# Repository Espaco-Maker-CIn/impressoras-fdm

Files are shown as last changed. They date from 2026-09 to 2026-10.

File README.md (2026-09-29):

# Documentação do Laboratório

Repositório central de manuais, configurações e instruções.
Se você não sabe por onde começar, use o índice abaixo.

## Impressoras 3D (kit Klipper + Orbiter)

Todas as impressoras usam o mesmo kit de upgrade. Manuais e
configurações de cada máquina estão em [printer](printers).

- [Manual de revitalização (PDF)](printers/manual-revitalizacao.pdf)
- [Manual de instalação do printer.cfg](printers/manual-instalacao-cfg.md)
- [Configuração de cada impressora](printers/configs)

## Adaptações 3D

Adaptações que foram feitas para impressoras:
[adaptacoes-3d](adaptacoes-3d)

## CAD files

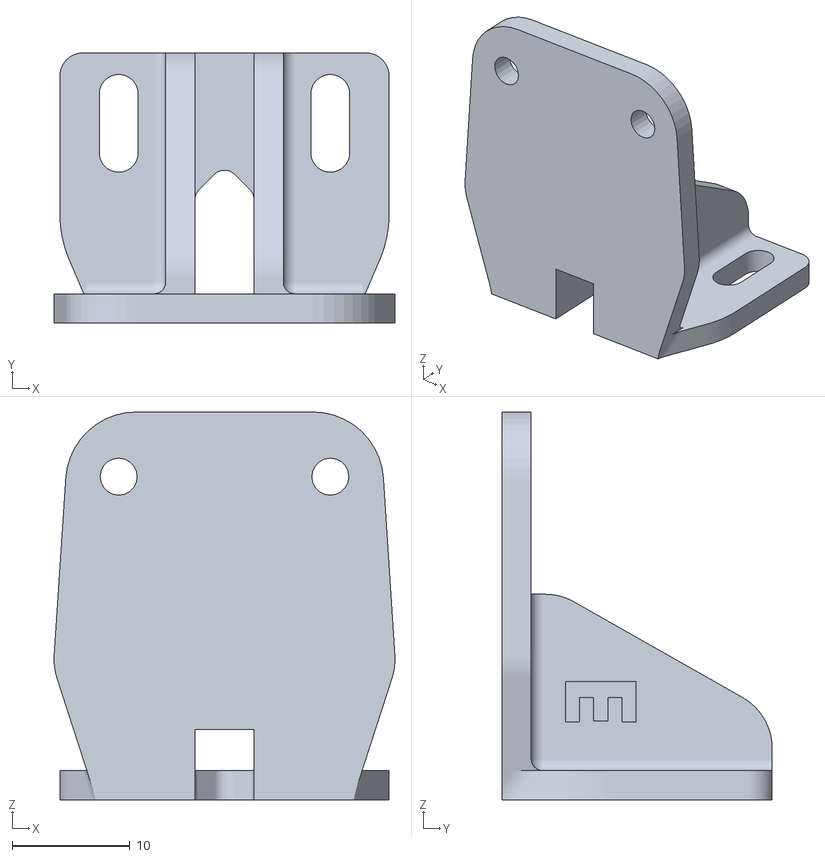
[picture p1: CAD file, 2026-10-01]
adaptacoes-3d/DDE BLtouch_adjustablev1.stl
29.0 x 23.0 x 33.0

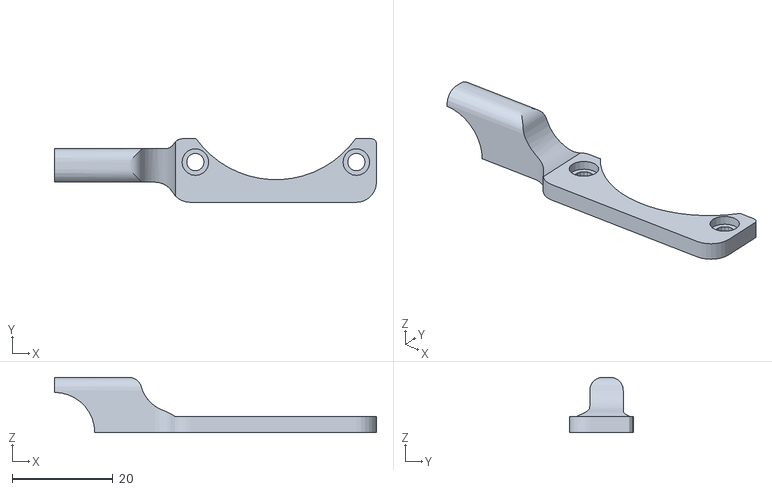
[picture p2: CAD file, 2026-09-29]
adaptacoes-3d/ender-3-v2-neo-fim-de-curso-X/adaptador-fim-de-curso-X.stl
64.0 x 12.6 x 11.0

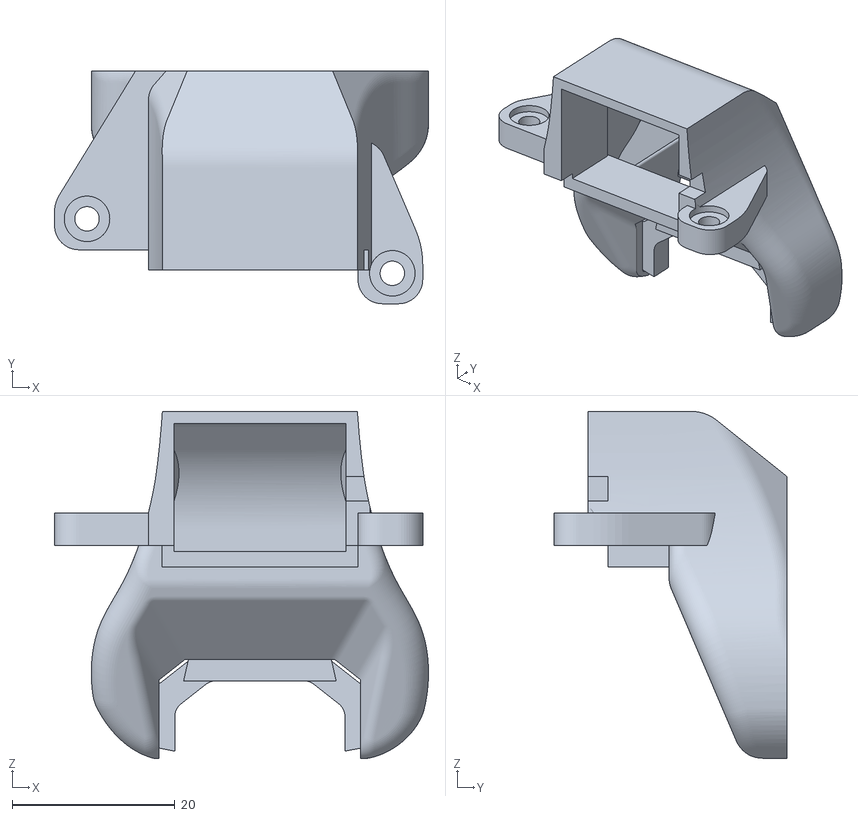
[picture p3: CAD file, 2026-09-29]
adaptacoes-3d/DDE-fan-shroud-volcano-V1.5.STL
46.0 x 28.6 x 42.7

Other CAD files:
adaptacoes-3d/ender-3-v2-neo-fim-de-curso-X/40x40x10 DC Fan.ipt
adaptacoes-3d/ender-3-v2-neo-fim-de-curso-X/OldVersions/40x40x10 DC Fan.0001.ipt

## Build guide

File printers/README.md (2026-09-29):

# Impressoras 3D: kit Klipper + Orbiter

## Manuais

- [Revitalização (PDF)](manual-revitalizacao.pdf): serve para todas as máquinas.
- [Instalação do printer.cfg](manual-instalacao-cfg.md): serve para todas as máquinas.

## Máquinas

| Etiqueta | Modelo | Arquivo de configuração | Observações |
|---|---|---|---|
| ender-3-v2-00 | Ender 3 V2 | [configs/ender-3-v2-00.cfg](configs/ender-3-v2-00.cfg) | |
| ender-3-v2-01 | Ender 3 V2 | [configs/ender-3-v2-01.cfg](configs/ender-3-v2-01.cfg) | |
| ender-3-v2-neo-00 | Ender 3 V2 Neo | [configs/ender-3-v2-neo-00.cfg](configs/ender-3-v2-neo-00.cfg) | |
| ender-3-v2-neo-01 | Ender 3 V2 Neo | [configs/ender-3-v2-neo-01.cfg](configs/ender-3-v2-neo-01.cfg) | |
| ender-7 | Ender 7 | [configs/ender-7.cfg](configs/ender-7.cfg) | |
| ender-5 | Ender 5 | [configs/ender-5.cfg](configs/ender-5.cfg) | |

## Regras para o printer.cfg

- Um arquivo por máquina, com o mesmo nome da etiqueta colada nela.
- Ao mudar algo, escreva no commit qual máquina e o motivo.
- Não coloque senhas nem dados de rede nos arquivos!

## O kit upgrade:

Todas as impressoras foram convertidas com o mesmo kit:

- Firmware: Klipper
- Extrusor: direct drive Orbiter
- Hotend: tipo V6 / Volcano
- Placa controladora: BIGTREETECH SKR Mini E3 V3.0
- Computador de bordo: Raspberry Pi executando o Klipper

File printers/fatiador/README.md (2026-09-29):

# Perfis do fatiador

Perfis prontos para importar no fatiador. Eles são independentes do
`printer.cfg`, mas trabalham em conjunto com ele.

## Fatiador usado

- Nome e versão: OrcaSlicer 4.2.4

## Como importar

1. Baixe os arquivos da pasta do fatiador.
2. No fatiador, importe primeiro o perfil da **impressora**,
   depois os de **filamento** e **qualidade**.
3. Selecione o conjunto correto na tela principal antes de fatiar.

## Perfis disponíveis

### Impressora

| Arquivo | Modelo | Observações |
|---|---|---|
| ender-3-v2.json | Ender 3 V2 | |
| ender-3-v2-neo.json | Ender 3 V2 Neo | |
| ender-7.json | Ender 7 | |
| ender-5.json | Ender 5 | |

### Filamento

| Arquivo | Material | Marca testada | Hotend | Temperatura bico / mesa |
|---|---|---|---|---|
| pla.json | PLA | (preencher) | V6 / Volcano | (preencher) |
| petg.json | PETG | (preencher) | V6 / Volcano | (preencher) |

### Qualidade

| Arquivo | Altura de camada | Uso recomendado |
|---|---|---|
| 0.12mm-fino.json | 0,12 mm | Detalhes finos |
| 0.20mm-padrao.json | 0,20 mm | Uso geral |
| 0.28mm-rapido.json | 0,28 mm | Protótipos rápidos |

## Ligação com o printer.cfg

- O G-code inicial dos perfis de impressora chama: (preencher, ex.: START_PRINT)
- Se mudar a macro no `printer.cfg`, atualize o perfil da impressora também.

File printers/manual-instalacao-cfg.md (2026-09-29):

# Instalação do printer.cfg

Este manual vale para todas as impressoras do kit Klipper + Orbiter.

## Antes de começar

- Klipper já instalado no Raspberry Pi
- Placa SKR Mini E3 V3.0 com o firmware do Klipper gravado
- Acesso à interface web (Mainsail)

## Passo a passo

1. Abra a interface web da impressora (com o IP dela).
2. No painel esquerdo procure por (Machine ou Maquina).
3. Substitua o conteúdo do `printer.cfg` pelo arquivo da sua máquina,
   em `printer/configs/`. (nao exclua o printer.cfg, no lugar, acesse-o e substitua o conteudo com ctrl+A + ctrl+V).
4. Clique em salvar e reiniciar (Save & Restart).
5. Confira se a impressora conecta sem erros.

## O que ajustar depois de instalar

- (preencher: calibração do Z offset, PID, esteps do extrusor...)

## Problemas comuns

- (preencher conforme aparecerem)

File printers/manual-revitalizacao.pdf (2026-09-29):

# Manual de Uso Simples

# Revitalização Impressora 3d

# Manual de Uso Simples

# Revitalização Impressora 3d

## Recife | 2026

## Edmundo Paiva

## Pedro Salman

## Coordenação de Extensão

©2026 by Centro de Informática - UFPE

## EXPEDIENTE

Reitor: Alfredo Macedo Gomes
Diretor do Centro de Informático: Sérgio Soares Vice-Diretor do Centro de Informático: Ricardo Massa Coordenador: Felipe Calegario

Apoio Técnico
Centro de Informática - UFPE

GUIA DO INICIANTE FABLAB:

ImprEssOrA 3D

Uma impressora 3D é, na prática, um conjunto de sistemas que precisam trabalhar de

forma integrada. Estrutura mecânica, eletrônica, firmware, motores, sensores e controle

térmico dependem uns dos outros para que uma peça seja produzida com qualidade e

segurança. Quando um desses sistemas se torna limitado ou obsoleto, muitas vezes

não | é necessário | substituir | toda | a | máquina: é possível | compreender | seu

funcionamento, identificar suas limitações e modernizá-la.

É justamente essa proposta que orienta este manual. A revitalização apresentada aqui

envolve a substituição de componentes mecânicos e eletrônicos da impressora, com a

instalação de um sistema de extrusão Direct Drive utilizando o Orbiter, hotend Volcano,

placa controladora BIGTREETECH SKR Mini E3 V3.0 e uma Raspberry Pi executando o

Klipper. O objetivo não é apenas fazer a impressora voltar a funcionar, mas transformá-

la em uma plataforma mais atual, configurável e adequada às necessidades do Espaço

Maker.

Durante o processo, diferentes áreas da engenharia se encontram. É necessário

compreender | montagem | mecânica, ajustes, organização | de | cabos, alimentação

elétrica, comunicação entre dispositivos, sistemas Linux e configuração de firmware.

Cada etapa permite observar como decisões aparentemente simples podem influenciar

diretamente o funcionamento e o desempenho final do equipamento.

Esse tipo de atividade representa bem a proposta do Espaço Maker: aprender

entendendo o equipamento, desmontando, modificando, testando e documentando

cada solução encontrada. Mais do que seguir uma sequência de montagem, este

manual busca registrar um processo que possa ser reproduzido, compreendido e

aprimorado por outras pessoas no futuro.

# Apresentação

Pedro Salman

Manager do Espaço Maker 2026

# Sumário

GUIA DO INICIANTE FABLAB:

ImprEssOrA 3D

1. Introdução
2. Lista de Materiais
3. Hardware

3.1 Preparação do conjunto do cabeçote

3.2 Substituição do carro de movimentação do eixo X

3.3 Instalação das porcas nas peças impressas

3.4 Instalação do ventilador 4010

3.5 Montagem das peças impressas e adaptação para o hotend Volcano

3.6 Fixação da base no carro de movimentação

3.7 Instalação do hotend Volcano

3.8 Instalação do tubo de PTFE

3.9 Fechamento do cabeçote

3.10 Instalação do extrusor Orbiter

3.11 Instalação do duto de ventilação e ventilador 5015

3.12 Organização do chicote

3.13 Conexões na BTT SKR Mini E3 V3.0

4. Firmware

4.1 Funcionamento do sistema Klipper

4.2 Preparação do cartão microSD

4.3 Instalação do MainsailOS

4.4 Configuração inicial do MainsailOS

4.5 Primeiro boot da Raspberry Pi

4.6 Identificação do endereço IP da Raspberry Pi

4.7 Acesso à Raspberry Pi por SSH

4.8 Instalação do KIAUH

4.9 Atualização dos componentes

4.10 Configuração do firmware da BTT SKR Mini E3 V3.0

4.11 Compilação e transferência do firmware com WinSCP

4.12 Gravação do firmware na BTT SKR Mini E3 V3.0

4.13 Conexão da Raspberry Pi à BTT SKR Mini E3 V3.0

4.14 Identificação da MCU

# Sumário

# Introdução

GUIA DO INICIANTE FABLAB:

ImprEssOrA 3D

# 1 Introdução

Este | manual | apresenta | o | procedimento | de | montagem | e | configuração | do | sistema

klipper+orbiter, utilizado na impressora 3D equipada com extrusor direct drive Orbiter, hotend

do tipo V6/Volcano, placa controladora BIGTREETECH SKR Mini E3 V3.0 e Raspberry Pi

executando o sistema Klipper.

O procedimento foi dividido em duas etapas principais: Hardware e Firmware.

Na primeira parte são apresentados os procedimentos necessários para montagem do carro de

movimentação, instalação do hotend, extrusor Orbiter, ventiladores e organização dos cabos.

Ao final, são apresentadas as conexões elétricas necessárias entre o novo conjunto e a placa

controladora.

Na segunda parte é apresentada a instalação do Klipper, começando pela preparação da

Raspberry Pi com o MainsailOS, configuração da rede, acesso via SSH, utilização do KIAUH e

compilação do firmware específico para a placa SKR Mini E3 V3.0.

O objetivo é permitir que todo o processo seja realizado de forma padronizada e reproduzível,

evitando erros de montagem, conexões incorretas e configurações incompatíveis entre a

Raspberry Pi e a placa controladora.

# Lista de Materiais

# 2 Lista de Materiais

Para a montagem do cabeçote serão utilizados:

Carro de movimentação compatível com Ender 3;

conjunto de peças impressas do DDE;

extrusor Orbiter;

hotend Volcano;

tubo de PTFE;

duto de ventilação;

porcas M3 quadradas;

porcas M3 sextavadas;

parafusos M3;

abraçadeiras plásticas;

malha para organização dos cabos.

kit duplo z, caso a impressora não possua (https://www.youtube.com/watch?v=rGkWkHWJFVs&t=322s)

Os componentes eletrônicos que serão utilizados:

placa BIGTREETECH SKR Mini E3 V3.0;

Raspberry Pi;

cartão microSD para a Raspberry Pi;

cartão microSD para a placa controladora;

ventilador axial 4010;

ventilador radial 5015;

motor do extrusor Orbiter;

cartucho aquecedor do hotend;

termistor;

cabo USB para comunicação entre a Raspberry Pi e a SKR Mini E3 V3.0.

Para utilização da Raspberry Pi 2 através de rede sem fio também será necessário um adaptador

Wi-Fi USB compatível com Linux. Alternativamente, a configuração inicial pode ser realizada por

conexão Ethernet.

As ferramentas necessárias para a montagem serão utilizadas principalmente:

chaves Allen;

chave Phillips;

alicate de corte;

abraçadeiras;

paquímetro;

ferramenta para acabamento da peça impressa;

computador com leitor de cartão microSD.

# Hardware

# 3 Hardware

3.1 Preparação do conjunto do cabeçote

Antes de realizar qualquer montagem ou alteração elétrica, desligue completamente a

impressora e desconecte-a da alimentação.

Nunca conecte ou desconecte motores de passo com a placa energizada.

Antes da montagem, confira todos os componentes do conjunto.

Verifique principalmente se as peças impressas não apresentam trincas, deformações ou

problemas nos alojamentos destinados às porcas.

Separe os parafusos e porcas por tamanho para facilitar as próximas etapas.

A TriangleLab recomenda realizar essa inspeção antes da montagem e começar pela

preparação das peças superior e inferior do cabeçote.

Figura 1: Componentes utilizados na montagem do cabeçote

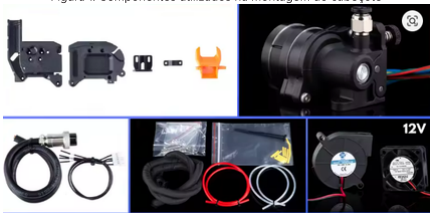
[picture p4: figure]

3.2 Substituição do carro de movimentação do eixo X

O primeiro passo da modificação será substituir o carro de movimentação atualmente instalado

pelo carro utilizado na Ender 3, necessário para fixação correta do conjunto DDE.

Passo a passo

1.Retire o cabeçote atualmente instalado.

2.Libere os cabos presos ao carro.

3.Solte a correia do eixo X.

4.Retire o carro de movimentação existente.

5.Instale o carro de movimentação da Ender 3.

6.Reinstale a correia.

7.Ajuste a porca excêntrica das rodas até eliminar a folga.

8.Movimente manualmente o carro por todo o eixo X.

O carro deve movimentar-se livremente, sem folgas e sem exigir força excessiva.

Figura 2: Verificação do movimento do novo carro

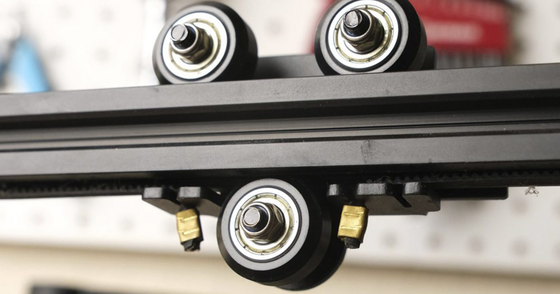
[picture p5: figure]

3.3 Instalação das porcas nas peças impressas

As peças impressas possuem alojamentos destinados às porcas utilizadas posteriormente na

montagem.

Existem alojamentos para porcas quadradas e sextavadas.

Passo a passo:

1.Identifique todos os alojamentos presentes nas peças.

2.Insira as porcas M3 quadradas nos alojamentos correspondentes.

3.Insira as porcas M3 sextavadas nos alojamentos sextavados.

4.Pressione as porcas até o fundo.

5.Caso seja necessário, utilize um parafuso M3 longo para auxiliar no encaixe.

6.Confirme que as porcas estão alinhadas e firmemente presas.

Essa preparação segue a montagem original da TriangleLab, que utiliza porcas M3 inseridas

diretamente nas cavidades das peças impressas.

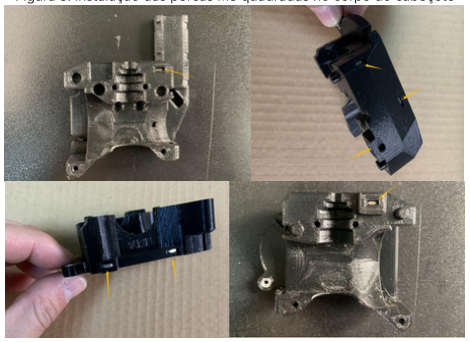
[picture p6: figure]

Figura 3: Instalação das porcas M3 quadradas no corpo do cabeçote

Figura 4: Instalação das porcas M3 quadradas no corpo do cabeçote

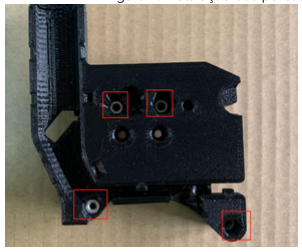
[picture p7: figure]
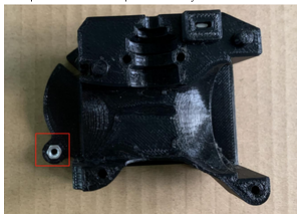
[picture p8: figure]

3.4 Instalação do ventilador 4010

O ventilador axial 4010 é responsável pela refrigeração da região fria do hotend.

Passo a passo

1.Posicione o ventilador no alojamento lateral da base.

2.Verifique o sentido do fluxo de ar.

3.Passe o cabo pelo canal horizontal existente na peça.

4.Fixe inicialmente o ventilador utilizando os parafusos M3 14 mm.

O manual original também direciona os fios do 4010 pelo canal lateral da peça antes do

fechamento do cabeçote.

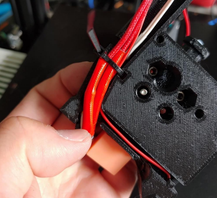
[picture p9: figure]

Figura 5: Ventilador 4010 instalado na base

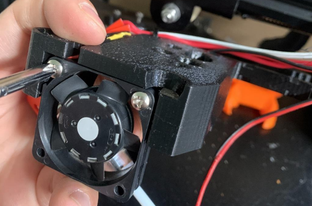
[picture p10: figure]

3.5 Montagem das peças impressas na base

Após a instalação das porcas, as diferentes peças impressas que compõem a estrutura interna

deverão ser inseridas na base do cabeçote.

Passo a passo:

1.Realize a adaptação para o hotend volcano, no ponto onde a entrada pneumatica tocaria.

2.Identifique a orientação de cada peça.

3.Posicione a primeira peça no encaixe correspondente.

4.Alinhe os furos com as porcas instaladas anteriormente.

5.Instale os parafusos necessários inicialmente sem realizar o aperto final.

6.Verifique se todas as peças estão completamente encaixadas e realize o ultimo aperto.

Figura 6: Peças impressas instaladas na base do cabeçote

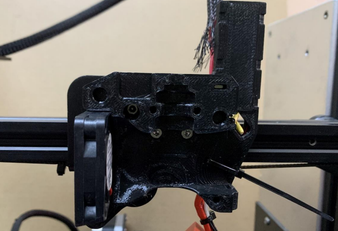
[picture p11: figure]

3.6 Instalação do hotend Volcano

Após realizar a adaptação da peça interna, o hotend Volcano poderá ser instalado.

Passo a passo

1.Posicione o hotend no alojamento.

2.Confirme o encaixe na peça adaptada.

3.Passe os fios do cartucho aquecedor pelo canal destinado ao chicote.

4.Passe também os fios do termistor.

5.Organize os cabos dentro da peça, eles nao podem estar dobrados.

6.Utilize uma abraçadeira para mantê-los posicionados.

7.Confirme que nenhum cabo encosta diretamente no bloco aquecedor.

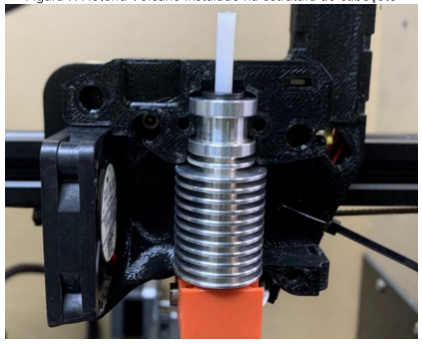
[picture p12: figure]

Figura 7: Hotend Volcano instalado na estrutura do cabeçote

3.7 Instalação do tubo de PTFE

O tubo de PTFE fará a ligação entre o extrusor Orbiter e o hotend.

Passo a passo

1.Corte o PTFE perpendicularmente.

2.Insira o tubo completamente no hotend.

3.Posicione temporariamente o Orbiter sobre o conjunto.

4.Verifique o comprimento necessário.

5.Ajuste o tubo de forma que não exista folga entre o extrusor e o hotend.

No conjunto V6 original, a TriangleLab especifica tubo de aproximadamente 52 a 52,5 mm, com

aproximadamente 11 mm expostos acima do corpo.

Como neste projeto a peça interna será modificada para o Volcano, essa dimensão deverá ser

confirmada no conjunto real antes de ser utilizada como medida definitiva.

Figura 8: Verificação do tubo de PTFE

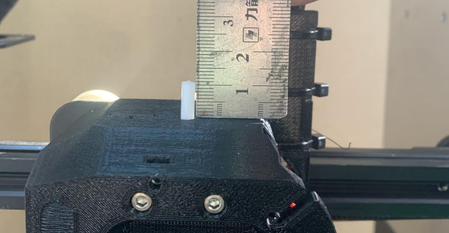
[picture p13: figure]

3.8 Fechamento do cabeçote

Após verificar a posição dos componentes internos, feche o conjunto.

Passo a passo

1.Organize os cabos dentro dos canais.

2.Verifique se nenhuma porca saiu do alojamento.

3.Posicione a parte superior do cabeçote.

4.Instale os quatro parafusos M3 × 35.

5.Aperte-os alternadamente.

6.Finalize a fixação do ventilador 4010.

A montagem original utiliza quatro parafusos M3 × 35 para unir as partes superior e inferior.

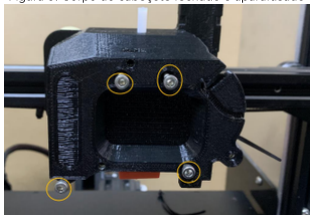
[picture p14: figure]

O Orbiter será instalado diretamente acima do hotend, formando o sistema Direct Drive.

Passo a passo

1.Caso o orbiter esteja desmontado, monte ele junto a caixa planetaria de redução, de forma

com que os cabos saiam para cima. As engrenganes devem engrenar suavemente.

2.Posicione o extrusor sobre o cabeçote.

3.Alinhe a saída do filamento com o tubo de PTFE.

4.Encaixe cuidadosamente o tubo.

5.Instale os dois parafusos M3 × 10.

6.Aperte os parafusos.

7.Verifique se o caminho do filamento está alinhado.

A TriangleLab utiliza dois parafusos M3 × 10 para realizar essa fixação.

Figura 9: Corpo do cabeçote fechado e aparafusado

3.9 Instalação do extrusor Orbiter

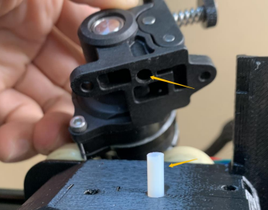
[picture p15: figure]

Figura 10: Extrusor Orbiter instalado sobre o cabeçote

3.10 Instalação do duto de ventilação

O duto direciona o ar proveniente do ventilador 5015 para a região de impressão.

Passo a passo

1. Imprima o duto para o extrusor volcano, ele se encontra anexado nessa mensagem. (https://drive.google.com/drive/folders/1piNkyhIdt_dpDcW6czVUYIUVgL8tmZOw)

2.Posicione o duto na parte inferior do cabeçote.

3.Alinhe seus pontos de fixação.

4.Instale os parafusos M3 × 10.

5.Verifique a posição da saída de ar.

6.Confirme que o duto não encosta no bloco aquecedor do Volcano.

7.Instale em seguida o ventilador 5015, e a fixe em seus repectivos parafusos.

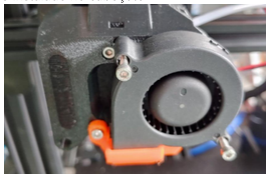
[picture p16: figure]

Figura 11: Duto e ventilador 5015 instalado no cabeçote

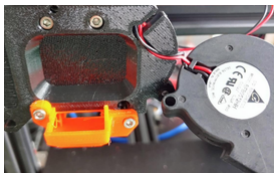
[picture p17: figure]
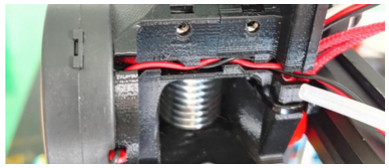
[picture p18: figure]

3.11 Organização do chicote

Todos os cabos do cabeçote deverão ser organizados formando um único chicote.

Passo a passo

1.Agrupe os fios do motor, ventiladores, termistor e cartucho aquecedor.

2.Posicione o elemento de sustentação do chicote.

3.Passe os cabos pela malha de proteção.

4.Fixe a malha ao cabeçote utilizando abraçadeiras.

5.Movimente manualmente o eixo X de uma extremidade à outra.

6.Verifique se o chicote acompanha todo o movimento sem ser tensionado.

7.Confirme que nenhum fio toca as rodas do carro.

O manual da TriangleLab chama atenção especificamente para evitar que os fios do motor

encostem nas rodas ou no perfil do eixo X.

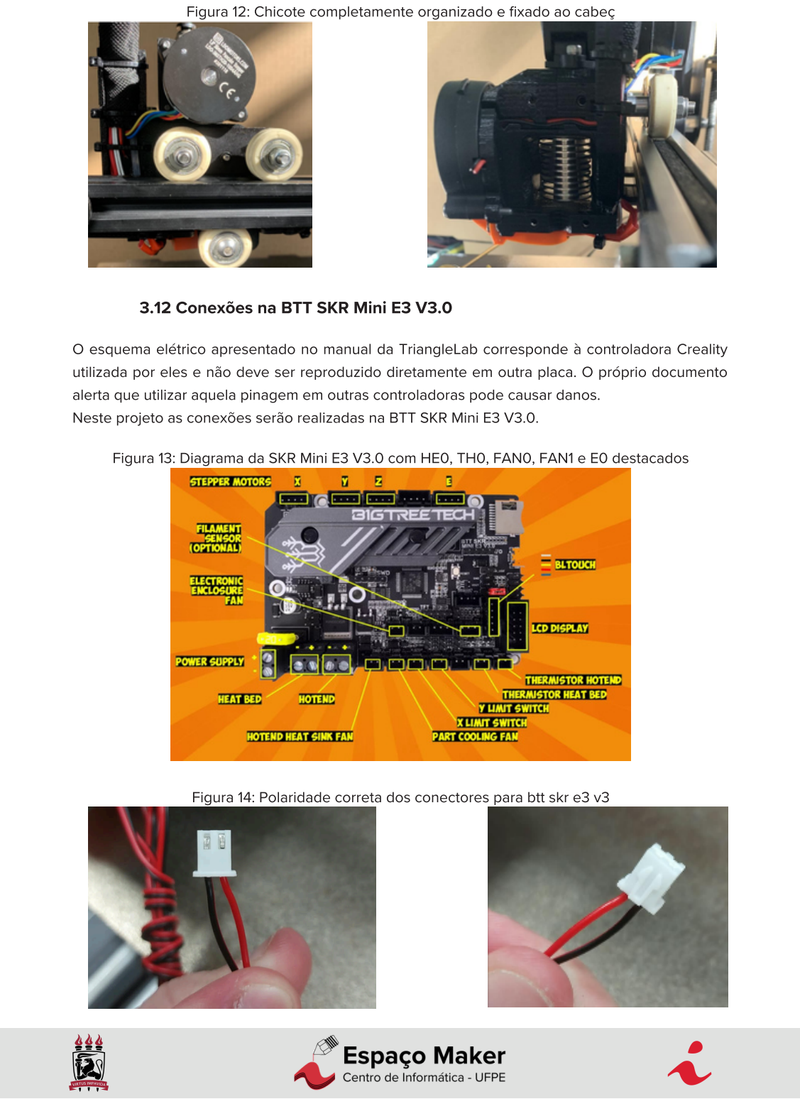
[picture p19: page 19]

O esquema elétrico apresentado no manual da TriangleLab corresponde à controladora Creality

utilizada por eles e não deve ser reproduzido diretamente em outra placa. O próprio documento

alerta que utilizar aquela pinagem em outras controladoras pode causar danos.

Neste projeto as conexões serão realizadas na BTT SKR Mini E3 V3.0.

Figura 12: Chicote completamente organizado e fixado ao cabeç

3.12 Conexões na BTT SKR Mini E3 V3.0

Figura 13: Diagrama da SKR Mini E3 V3.0 com HE0, TH0, FAN0, FAN1 e E0 destacados

Figura 14: Polaridade correta dos conectores para btt skr e3 v3

# Firmware

N (https://raspberry-pi-imager.br.uptodown.com/windows/download/109117164)o Raspberry Pi Imager, versão 1.7.5: (https://raspberry-pi-imager.br.uptodown.com/windows/download/109117164)

1.Selecione o sistema operacional.

2.Acesse Other specific-purpose OS.

3.Selecione a categoria destinada à impressão 3D.

4.Selecione MainsailOS.

5.Escolha a versão compatível com a Raspberry Pi utilizada.

6.Selecione o cartão microSD.

Essa é a sequência apresentada no vídeo utilizado como referência para a instalação.

Para a Rasp 2, é utilizado o mainsail 32bits, mas para outras placas, costumam se utilizar sistemas

64bits.

Será utilizado um cartão microSD para armazenar o sistema operacional da Raspberry Pi.

Passo a passo

1.Insira o cartão no computador.

2.Abra o Raspberry Pi Imager.

3.Confirme se o cartão correto foi reconhecido.

4.Prepare-se para selecionar o MainsailOS.

A gravação apagará os arquivos existentes no cartão.

# 4 Firmware

4.1 Preparação do cartão microSD

O sistema será dividido entre a Raspberry Pi e a placa controladora.

A Raspberry Pi executará os serviços responsáveis pelo Klipper (https://www.youtube.com/watch?v=_8r87gBFOy8) e pela interface de controle.

A SKR Mini E3 V3.0 executará o firmware da MCU e ficará responsável pelo controle direto dos

motores, aquecedores, sensores e ventiladores.

A comunicação entre os dois dispositivos será realizada por USB.

Figura 4: Tipos de solda

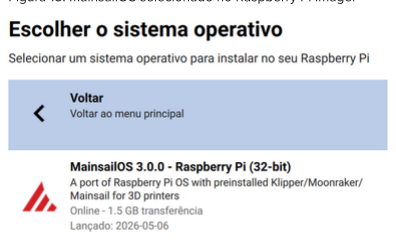
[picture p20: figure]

Figura 15: MainsailOS selecionado no Raspberry Pi Imager

4.2 Instalação do MainsailOS

4.3 Configuração inicial do MainsailOS

Antes de gravar o cartão, abra as opções de personalização.

Configure:

nome do dispositivo;

usuário;

senha;

acesso SSH;

rede, quando aplicável;

localização;

fuso horário.

O SSH deverá permanecer habilitado, pois será necessário posteriormente.

Figura 16: Configurações de hostname, usuário, rede e SSH

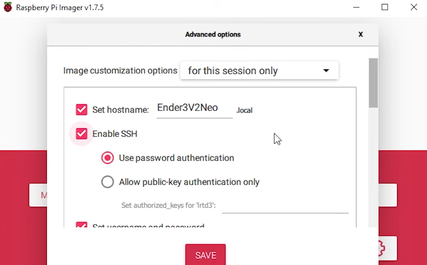
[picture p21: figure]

4.4 Primeiro boot da Raspberry Pi

Após concluir a gravação:

1.Remova o cartão do computador.

2.Insira-o na Raspberry Pi.

3.Conecte a Raspberry Pi à rede.

4.Conecte sua alimentação.

5.Aguarde a inicialização.

O primeiro boot poderá demorar alguns minutos.

4.5 Acesso ao Mainsail

Após concluir a gravação:

1.Conecte a rasp via ethernet ou wi-fi préconfigurada.

2.Conecte o cabo hdmi e teclado para conseguir digitar no terminal

3.coloque o login e senha, para logar.

4. Digite “ hostname -I “ para descobrir o ip da rede da rasp.( i maiusculo)
5. O ip será algo como 172.X.X.X.
6. Com esse ip, e quando estiver na mesma rede da rasp, voce consegue acessar via ssh.
7. Existe inumeros softwares para ter esse acesso, recomendo o putty. (https://www.chiark.greenend.org.uk/~sgtatham/putty/latest.html)

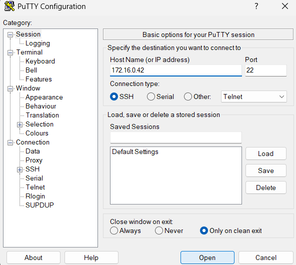
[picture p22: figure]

O KIAUH — Klipper Installation And Update Helper será utilizado para auxiliar na manutenção e

atualização dos componentes do sistema.

Primeiramente, atualize a lista de pacotes e instale o Git:

sudo apt-get update && sudo apt-get install git -y

Depois faça o download do KIAUH:

cd ~ && git clone https://github.com/dw-0/kiauh.git

Execute:

./kiauh/kiauh.sh

Esses são os comandos apresentados pelo próprio projeto KIAUH, e deve aparecer algo como:

Figura 17: Tela inicial Putty

4.6 Instalação do KIAUH

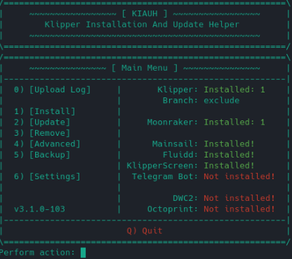
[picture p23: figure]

Figura 18: Tela inicial KIAUH

4.7 Atualização dos componentes

No menu principal do KIAUH, acesse a opção destinada às atualizações.

Verifique os componentes instalados e atualize os que apresentarem novas versões,

principalmente:

Klipper;

Moonraker;

Mainsail;

KIAUH.

Os números das opções podem variar entre versões. Por isso, utilize os nomes exibidos no menu

e não uma sequência numérica fixa.

O KIAUH identifica Klipper, Moonraker e Mainsail entre seus componentes principais.

Você deve precionar o numero 2 para ir ao menu de update, e lá, aceitar todos eles, isso irá

demorar alguns minutos.

Figura 19: Menu de atualização do KIAUH

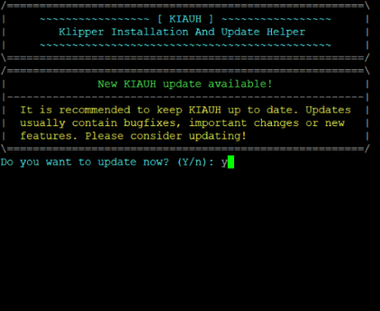
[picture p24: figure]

4.8 Configuração do firmware da SKR Mini E3 V3.0

Após as atualizações, acesse a pasta do Klipper:

cd ~/klipper

Execute:

make menuconfig

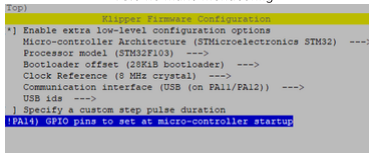
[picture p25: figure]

Com a configuração salva, execute:

make

Aguarde o término da compilação. O arquivo será gerado em: ~/klipper/out/klipper.bin

Esse arquivo está armazenado na Raspberry Pi e deverá ser transferido para o computador antes

de ser colocado no cartão microSD da SKR Mini E3 V3.0.

Para retirar o arquivo da Raspberry Pi será utilizado o WinSCP, (https://winscp.net/eng/download.php) que permite acessar os arquivos

da Raspberry Pi através da rede.

1.Abra o WinSCP no computador.

2.Na tela de conexão, selecione:

Protocolo de arquivo: SFTP

Nome do servidor: Utilize o endereço IP da Raspberry Pi 172.x.X.X

Porta: 22

1.Informe o mesmo usuário e senha utilizados para acessar a Raspberry Pi através do SSH.

2.Clique em Login.

Na primeira conexão poderá ser apresentada uma mensagem solicitando confirmação da chave

do servidor. Confirme para continuar.

Após a conexão, o WinSCP apresentará duas áreas principais:

lado esquerdo: arquivos do computador;

lado direito: arquivos da Raspberry Pi.

Para a BTT SKR Mini E3 V3.0, configure:

Enable extra low-level configuration options

Micro-controller Architecture

STMicroelectronics STM32

Processor model

STM32G0B1

Bootloader offset

8KiB bootloader

Clock Reference

8 MHz crystal

Communication interface

USB (on PA11/PA12)

Figura 20: Configuração da SKR Mini E3

V3.0 no make menuconfig

4.9 Compilação do firmware

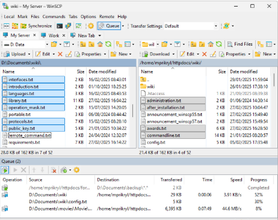
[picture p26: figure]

No lado correspondente à Raspberry Pi, acesse a pasta:

/home/USUARIO/klipper/out/

Localize o arquivo:

klipper.bin

No lado esquerdo do WinSCP, abra uma pasta do computador onde o arquivo será salvo.

Arraste o arquivo klipper.bin do lado da Raspberry Pi para o lado do computador.

Aguarde a conclusão da transferência.

O arquivo de firmware agora estará armazenado no computador e poderá ser preparado para

gravação na SKR Mini E3 V3.0.

Insira um cartão microSD no computador, formatado adequadamente, e coloque o firmware.bin

diretamente na raiz.

A SKR Mini E3 V3.0 necessita que o arquivo gerado pelo Klipper seja renomeado para

firmware.bin antes da atualização por cartão.

Figura 21: Transferência do klipper.bin utilizando o WinSCP

Passo a passo

1.Desligue completamente a impressora.

2.Insira o cartão microSD na SKR Mini E3 V3.0.

3.Ligue a impressora.

4.Aguarde a inicialização da placa.

5.Desligue novamente o equipamento.

Após a gravação, conecte a Raspberry Pi à interface Micro-USB da SKR Mini E3 V3.0. Utilize um

cabo USB capaz de transmitir dados. Ligue novamente os equipamentos.

4.10 Gravação do firmware na SKR Mini E3 V3.0

Abra o Mainsail via navegador ou orcaslicer.

A presença da SKR Mini E3 V3.0 no comando anterior confirma que:

a Raspberry Pi está operacional;

o Klipper está instalado;

o firmware da MCU foi compilado;

a SKR recebeu o firmware;

a comunicação USB está funcionando.

A configuração específica da impressora será realizada posteriormente através do arquivo

printer.cfg.

Nele serão configurados os motores, termistores, ventiladores, extrusor Orbiter, limites de

movimento e demais parâmetros da máquina.

4.11 Identificação da MCU

Acesse novamente a Raspberry Pi por SSH.

ls /dev/serial/by-id/*

Deverá aparecer um endereço semelhante a:

/dev/serial/by-id/usb-Klipper_stm32g0b1xx_XXXXXXXXXXXX-if00

Copie exatamente o endereço apresentado.

Posteriormente ele será inserido no printer.cfg, por exemplo:

[mcu]

serial: /dev/serial/by-id/usb-Klipper_stm32g0b1xx_XXXXXXXXXXXX-if00

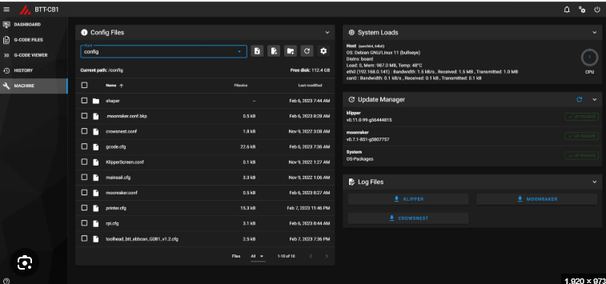
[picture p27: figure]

Figura 22: Interface do Mainsail

4.12 Configuração do firmware da SKR Mini E3 V3.0

©2026 by Centro de Informática - UFPE

# Manual de Uso Simples

# Revitalização Impressora 3d

## Recife | 2026

## Edmundo Paiva

## Pedro Salman

## Coordenação de Extensão

# Contato

## espacomaker.cin.ufpe.br

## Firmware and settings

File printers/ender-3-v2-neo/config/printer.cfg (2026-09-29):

# This file contains common pin mappings for the BIGTREETECH SKR mini
# E3 v3.0. To use this config, the firmware should be compiled for the
# STM32G0B1 with a "8KiB bootloader" and USB communication/USART.
#
# The "make flash" command does not work on the SKR mini E3. Instead,
# after running "make", copy the generated "out/klipper.bin" file to a
# file named "firmware.bin" on an SD card and then restart the SKR
# mini E3 with that SD card.
#
# See docs/Config_Reference.md for a description of parameters.


[include mainsail.cfg]


# ================================================================
# MCU
# ================================================================

[mcu]
serial: /dev/serial/by-id/usb-Klipper_stm32g0b1xx_390027000C50564837383420-if00
# serial: /dev/ttyAMA0
# restart_method: command


# ================================================================
# PRINTER
# ================================================================

[printer]
kinematics: cartesian
max_velocity: 300
max_accel: 5000
max_z_velocity: 5
max_z_accel: 70


# ================================================================
# EIXO X
# ================================================================

[stepper_x]
step_pin: PB13
dir_pin: !PB12
enable_pin: !PB14
microsteps: 16
rotation_distance: 40
endstop_pin: ^PC0
position_endstop: 0
position_max: 200
homing_speed: 50

[tmc2209 stepper_x]
uart_pin: PC11
tx_pin: PC10
uart_address: 0
run_current: 0.580
hold_current: 0.500
stealthchop_threshold: 0


# ================================================================
# EIXO Y
# ================================================================

[stepper_y]
step_pin: PB10
dir_pin: !PB2
enable_pin: !PB11
microsteps: 16
rotation_distance: 40
endstop_pin: ^PC1
position_endstop: 0
position_min: 0
position_max: 230
homing_speed: 50

[tmc2209 stepper_y]
uart_pin: PC11
tx_pin: PC10
uart_address: 2
run_current: 0.650
hold_current: 0.400
stealthchop_threshold: 0


# ================================================================
# EIXO Z + PROBE (BLTOUCH)
# ================================================================

[stepper_z]
step_pin: PB0
dir_pin: PC5
enable_pin: !PB1
microsteps: 16
rotation_distance: 8
endstop_pin: probe:z_virtual_endstop
position_max: 250
position_min: -5

[tmc2209 stepper_z]
uart_pin: PC11
tx_pin: PC10
uart_address: 1
run_current: 0.580
hold_current: 0.500
stealthchop_threshold: 999999

[bltouch]
sensor_pin: ^PC14
control_pin: PA1
x_offset: +42.5
y_offset: +0
#z_offset: 2.7
stow_on_each_sample: False
probe_with_touch_mode: True

[safe_z_home]
home_xy_position: 86.25, 105 # Posiciona o bico para que a sonda toque no centro exato da malha
speed: 50
z_hop: 10
z_hop_speed: 10


# ================================================================
# BED MESH
# ================================================================

[bed_mesh]
speed: 120
horizontal_move_z: 5
mesh_min: 42.5, 15        # X mínimo = 40 (impede o bico de tentar ir para X negativo)
mesh_max: 210, 225      # X máximo = 170 (impede o BLTouch de sair da mesa a direita)
probe_count: 5,5
# algorithm: bicubic  # DESCOMENTE CASO A MESH SEJA >= 7X7


# ================================================================
# EXTRUSORA
# ================================================================

[extruder]
step_pin: PB3
dir_pin: PB4
enable_pin: !PD1
microsteps: 16
full_steps_per_rotation: 200
rotation_distance: 4.73
nozzle_diameter: 0.400
filament_diameter: 1.750
max_extrude_only_distance: 500
max_extrude_only_velocity: 120
max_extrude_only_accel: 800
pressure_advance: 0.030
pressure_advance_smooth_time: 0.04
heater_pin: PC8
sensor_type: EPCOS 100K B57560G104F
sensor_pin: PA0
control: pid
pid_Kp: 32.424
pid_Ki: 2.324
pid_Kd: 113.078
min_temp: 0
max_temp: 270

[tmc2209 extruder]
uart_pin: PC11
tx_pin: PC10
uart_address: 3
run_current: 0.850
hold_current: 0.500
stealthchop_threshold: 0


# ================================================================
# MESA AQUECIDA
# ================================================================

[heater_bed]
heater_pin: PC9
sensor_type: ATC Semitec 104GT-2
sensor_pin: PC4
control: pid
pid_Kp: 64.850
pid_Ki: 1.024
pid_Kd: 1026.245
min_temp: 0
max_temp: 130


# ================================================================
# VENTOINHAS (Pins padrao SKR Mini E3 v3)
# ================================================================

[heater_fan controller_fan]
pin: PC7
heater: heater_bed
heater_temp: 45.0

[heater_fan nozzle_cooling_fan]
pin: PB15

[fan]
pin: PC6


# ================================================================
# DISPLAY / BOARD PINS / BEEPER
# ================================================================

[board_pins]
aliases:
    EXP1_1=PB5,  EXP1_3=PA9,  EXP1_5=PA10, EXP1_7=PB8, EXP1_9=<GND>,
    EXP1_2=PA15, EXP1_4=<RST>, EXP1_6=PB9, EXP1_8=PD6, EXP1_10=<5V>

[display]
lcd_type: emulated_st7920
spi_software_miso_pin: PD8
spi_software_mosi_pin: PD6
spi_software_sclk_pin: PB9
en_pin: PB8
encoder_pins: ^PA10, ^PA9
click_pin: ^!PA15

[output_pin beeper]
pin: PB5


# ================================================================
# MACROS
# ================================================================

[gcode_macro PRINT_START]
description: Inicio da impressao
gcode:
    {% set BED = params.BED|float %}
    {% set EXTRUDER = params.EXTRUDER|float %}

    M140 S{BED}
    M104 S180
	M190 S{BED}

    G28
	BED_MESH_CALIBRATE; mapeia a mesa

    M104 S{EXTRUDER}
    M109 S{EXTRUDER}

	G90
    M83
    G92 E0

    G1 Z2.0 F3000
    G1 X5 Y20 Z0.3 F5000

    ; purge line
    G1 X5 Y200 Z0.3 F1500 E15
    G1 X5.4 Y200 Z0.3 F5000
    G1 X5.4 Y20 Z0.3 F1500 E15

    G92 E0

[gcode_macro PRINT_END]
description: Finaliza a impressao e estaciona o cabeçote
gcode:
    M400
    G92 E0
    G1 E-7.0 F1800

    TURN_OFF_HEATERS
    M107

    G91
    G1 Z10 F3000
    G90

    G1 X200 Y200 F6000

    M84

[gcode_macro CANCEL_PRINT]
description: Cancela a impressao com seguranca dentro dos limites
rename_existing: BASE_CANCEL_PRINT
gcode:
    TURN_OFF_HEATERS
    M107
    CLEAR_PAUSE

    {% if "xyz" in printer.toolhead.homed_axes %}
      G91
      G1 Z10 F3000
      G90
      G1 X200 Y200 F6000
    {% endif %}

    BASE_CANCEL_PRINT

[gcode_macro _CLIENT_VARIABLE]
variable_park_at_cancel   : True
variable_user_cancel_macro: "_MANTER_TEMP_CANCEL"
gcode:

[gcode_macro _MANTER_TEMP_CANCEL]
gcode:
    M104 S180
    M140 S55


# ================================================================
# SAVE_CONFIG
# ================================================================

#*# <---------------------- SAVE_CONFIG ---------------------->
#*# DO NOT EDIT THIS BLOCK OR BELOW. The contents are auto-generated.
#*#
#*# [bltouch]
#*# z_offset = 1.620
#*#
#*# [bed_mesh default]
#*# version = 1
#*# points =
#*# 	  0.022500, -0.062500, -0.075000, -0.072500, -0.015000
#*# 	  -0.092500, -0.127500, -0.142500, -0.165000, -0.160000
#*# 	  -0.100000, -0.140000, -0.137500, -0.112500, -0.115000
#*# 	  -0.097500, -0.120000, -0.117500, -0.082500, -0.077500
#*# 	  0.007500, -0.005000, -0.027500, -0.025000, 0.075000
#*# x_count = 5
#*# y_count = 5
#*# mesh_x_pps = 2
#*# mesh_y_pps = 2
#*# algo = lagrange
#*# tension = 0.2
#*# min_x = 42.5
#*# max_x = 214.98
#*# min_y = 15.0
#*# max_y = 225.0

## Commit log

2026-09-29 adicionei varias instrucoes. faltam muitos ajustes textuais e arquivos do fatiador (configuracao do orca)
    [40x40x10 DC Fan.0001.ipt, 40x40x10 DC Fan.ipt, DDE-fan-shroud-volcano-V1.5.STL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]
2026-09-29 modifiquei os readme's para referenciar corretamente os arquivos
2026-10-01 versao stl ajustada do suporte bltouch
    [DDE BLtouch_adjustablev1.stl]
2026-10-02 add as configs do orca
    depois modifico para separar config de filamento, config de impressora e config de camada
2026-10-16 Add bl touch files
    Bl touch high calibration part.
